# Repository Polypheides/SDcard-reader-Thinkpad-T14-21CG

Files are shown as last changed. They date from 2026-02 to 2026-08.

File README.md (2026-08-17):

# ⚠️ Disclaimer: Rev. 7 PCB Tested with Known Issues ⚠️

**Use at your own risk.** This is an experimental project. Rev. 7 has been hardware-verified to work, but requires a bodge wire fix.

> [!IMPORTANT]
> <details>
>   <summary><b>View Rev. 7 Bodge Wire Photo</b></summary>
>   <br>
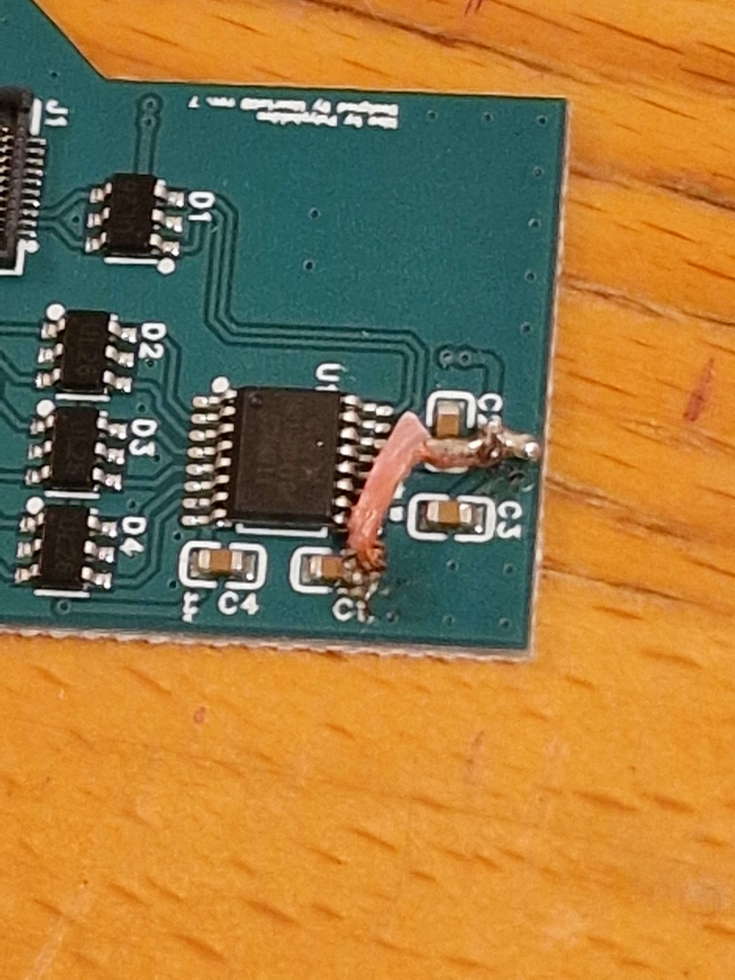
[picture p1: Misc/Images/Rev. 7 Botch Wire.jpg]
Rev. 7 Botch Wire
>   
> </details>

---

## Project Overview

This repository provides **Gerber files** for an internal MicroSD card reader daughterboard designed for the **ThinkPad T14 (Gen 3 / 21CG)**. It replaces the stock right-side single USB daughterboard.

### Technical Specifications

* **Controller:** Genesys Logic **GL823K** (USB 2.0 MicroSD Card Reader Controller).
* **ESD Protection:** **USBLC6-2SC6** monolithic ESD protection array.
  * **Data Integrity:** Ultra-low line capacitance (1 pF) prevents signal degradation on USB 2.0 differential pairs (D+/D-).
  * **Line Coverage:** Dedicated ESD clamping for data, clock, and command lines.
  * **Rail-to-Rail Clamping:** Suppresses high-voltage electrostatic discharge before transients reach the controller or internal hub.
* **Interface:** 20-pin FPC / board-to-board connector (`CON1`).
* **PCB Thickness:** Recommended **1.0 mm** for proper chassis clearance and alignment.

> [!NOTE]
> Rev.8 integrates the missing trace fix from Rev. 7 (eliminating the need for a jumper wire) and adds additional decoupling capacitors for power rail stability.

---

## Installation & Fitment Notes

* **Chassis Modification:** Physical filing or trimming of the laptop's plastic/magnesium subframe should not be required.
* **Connector Orientation:** Ensure **Pin 1** on the daughterboard aligns with **Pin 1** on the motherboard connector before applying power.

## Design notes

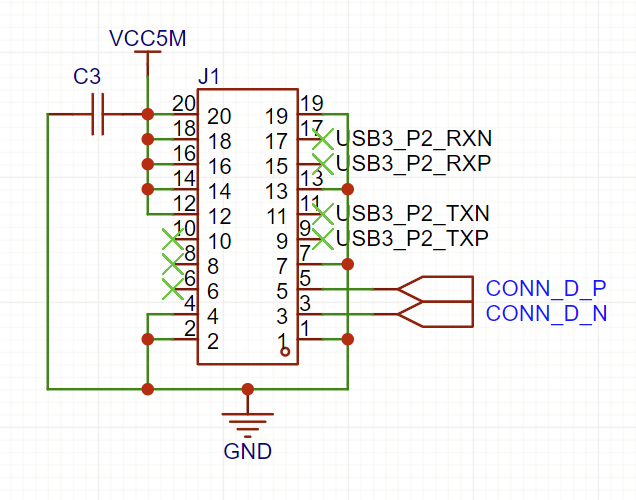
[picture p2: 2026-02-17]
Misc/Images/Connector Pinout.png

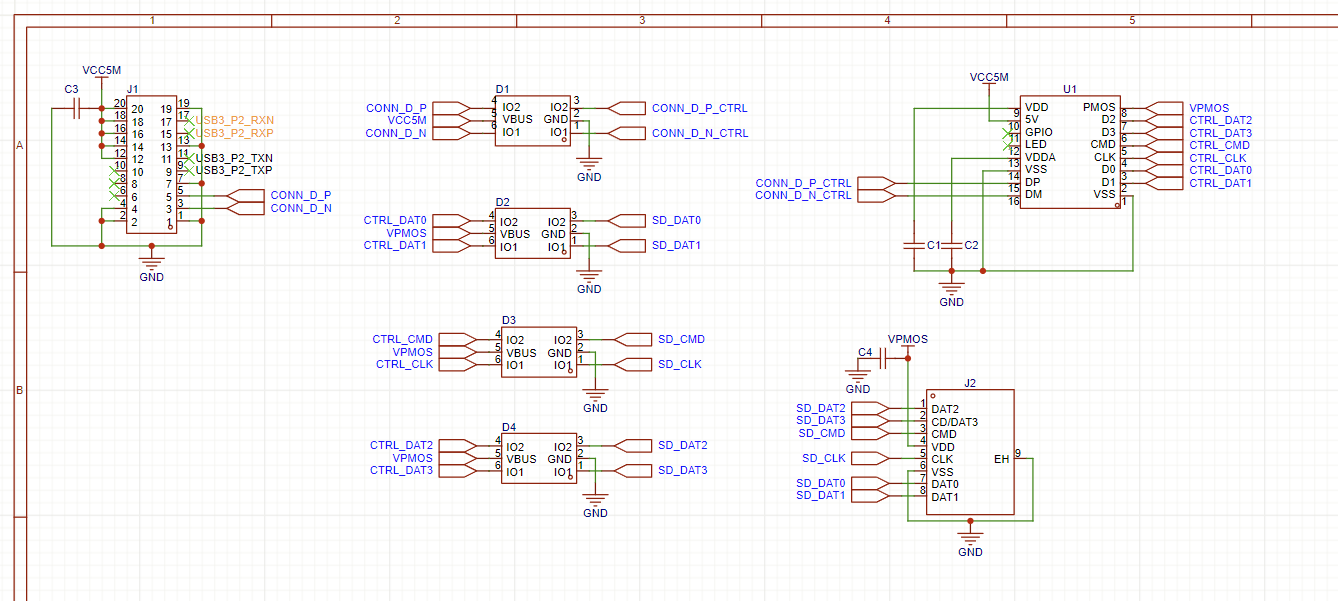
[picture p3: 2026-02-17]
Misc/Schematic/MuertoGB cleaned up Schematic.png

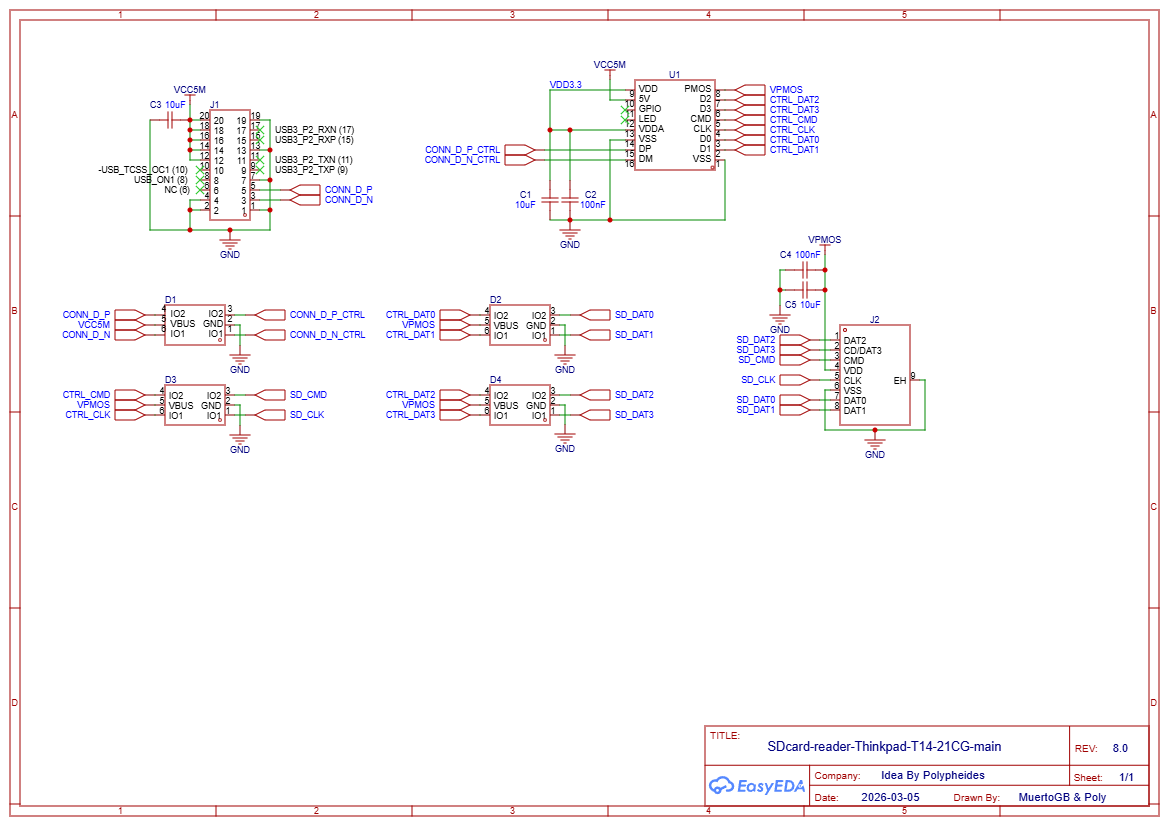
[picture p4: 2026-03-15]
Misc/Schematic/SCH_SD_pcb_t14_1-Sheet_1_2026-03-05.png

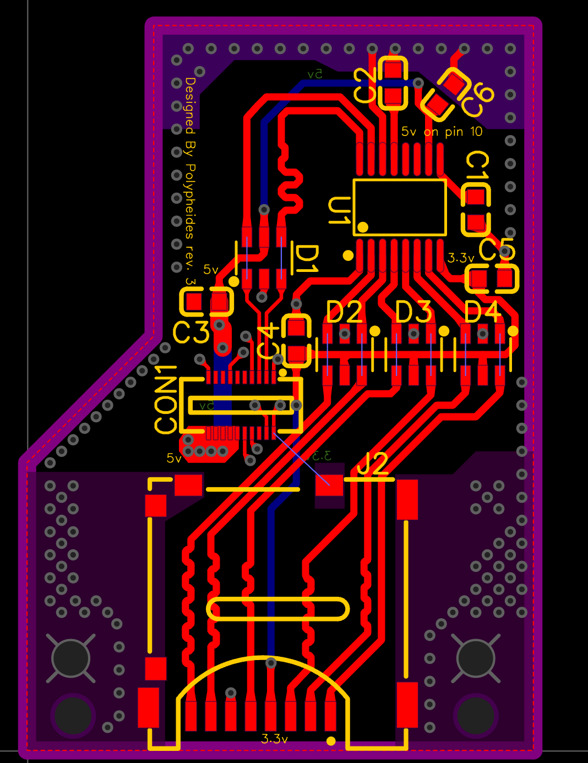
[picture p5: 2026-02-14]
Misc/Images/Rev3 example.png

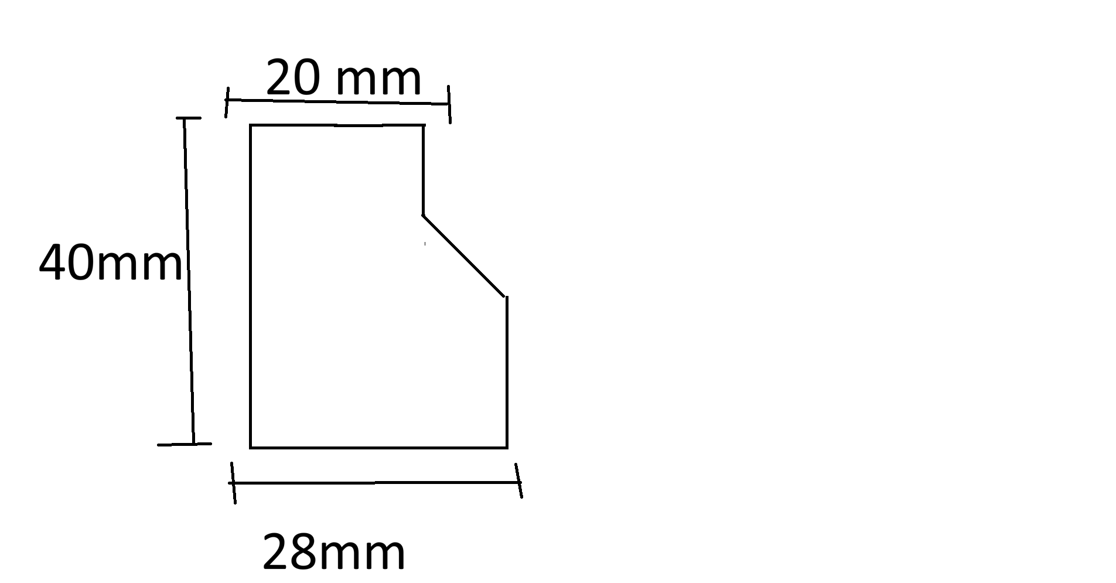
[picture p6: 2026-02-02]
Misc/Images/Dimentions.png

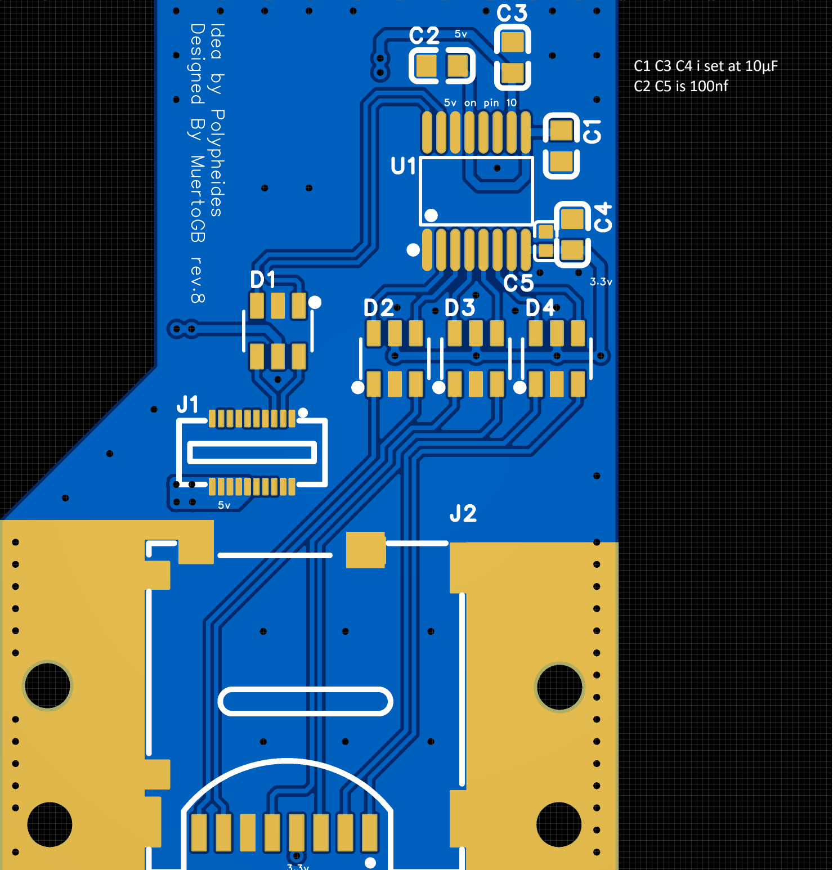
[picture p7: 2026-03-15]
Misc/Images/consept-of-Rev-8.png

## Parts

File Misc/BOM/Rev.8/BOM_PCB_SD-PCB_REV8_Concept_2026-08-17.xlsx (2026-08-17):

No. | Quantity | Comment | Designator | Footprint | Value | Manufacturer Part | Manufacturer | Supplier Part | Supplier
1 | 3 | 10uF | C1,C3,C4 | C0603 | 10uF | GRM188Z71A106KA73D | muRata(村田) | C2959727 | LCSC
2 | 1 | 100nF | C2 | C0603 |  | AC0603KRX7R8BB104 | YAGEO(国巨) | C327096 | LCSC
3 | 1 | 100nF | C5 | C0402 | 100nF | CC0402KRX7R7BB104 | YAGEO(国巨) | C60474 | LCSC
4 | 4 | USBLC6-2SC6_C2827654 | D1,D2,D3,D4 | SOT-23-6_L2.9-W1.6-P0.95-LS2.8-BL |  | USBLC6-2SC6 | TECH PUBLIC(台舟) | C2827654 | LCSC
5 | 1 | DF40C-20DS-0.4V(51) | J1 | CONN-SMD_20P-P0.40_DF40C-20DS-0.4V |  | DF40C-20DS-0.4V(51) | HRS(广濑) | C424638 | LCSC
6 | 1 | TF-009 | J2 | TF-SMD_TF-009 |  | TF-009 | SOFNG(硕方) | C428466 | LCSC
7 | 1 | GL823K-HCY04 | U1 | SSOP-16_L4.9-W3.9-P0.64-LS6.0-BL |  | GL823K-HCY04 | GENESYS(创惟) | C284879 | LCSC

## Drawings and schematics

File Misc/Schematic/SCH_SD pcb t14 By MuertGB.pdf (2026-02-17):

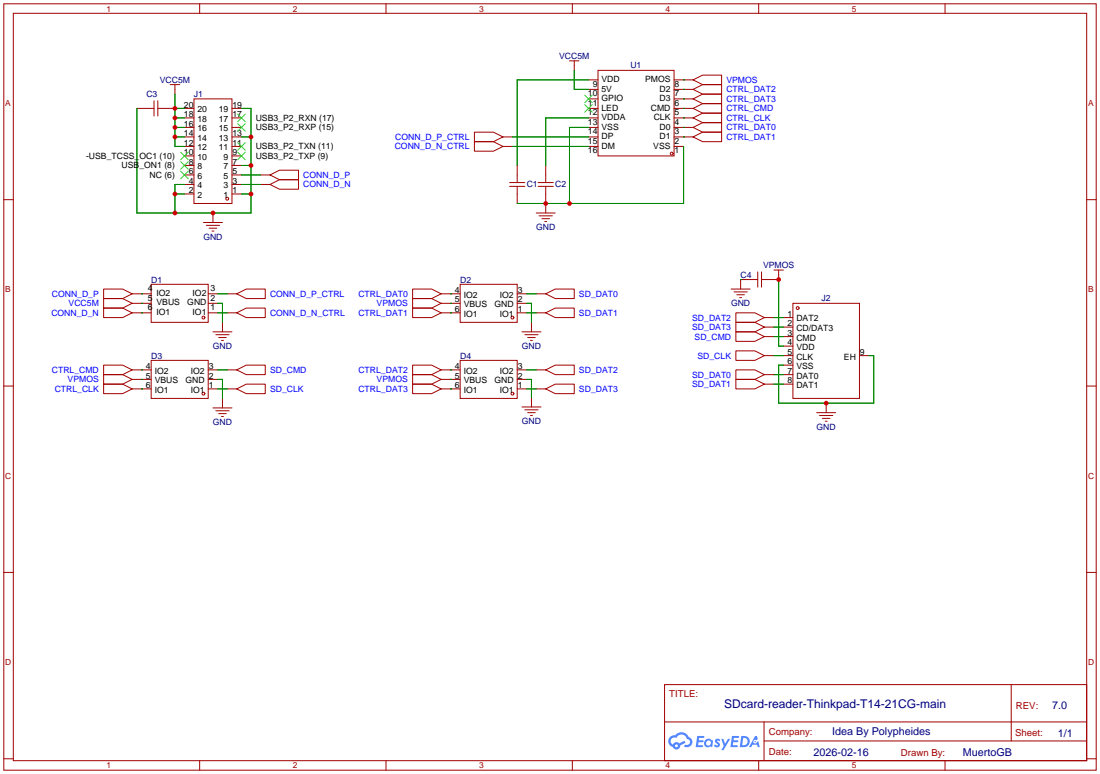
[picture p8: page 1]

VDD 9
5V 10 GPIO 11 LED 12 VDDA 13 VSS 14 DP 15 DM 16

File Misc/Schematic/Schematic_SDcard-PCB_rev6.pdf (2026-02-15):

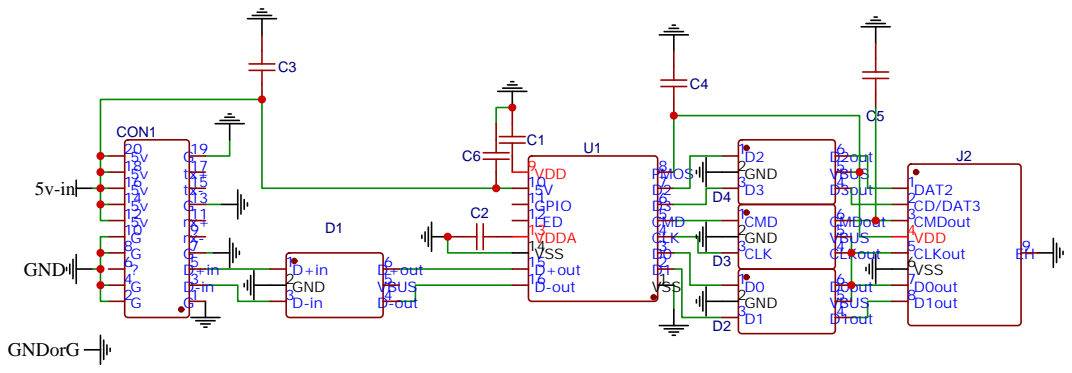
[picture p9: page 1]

Drawn By: Anders Johansson

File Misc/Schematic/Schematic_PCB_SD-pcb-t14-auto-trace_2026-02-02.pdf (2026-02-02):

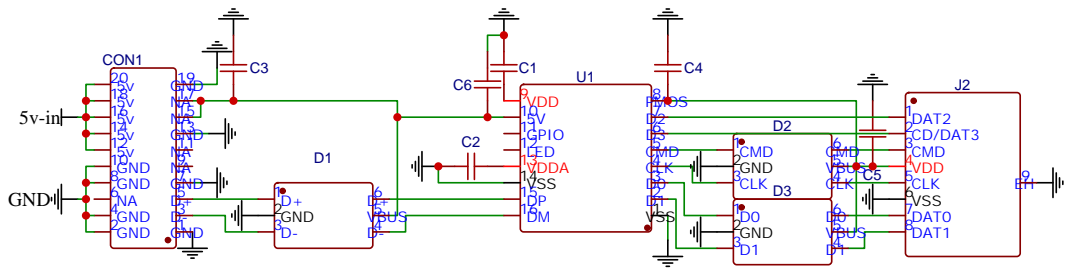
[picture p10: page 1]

Drawn By: Anders Johansson

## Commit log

2026-02-02 Initial Push
    [Drill_NPTH_Through.DRL, Drill_PTH_Through.DRL, Drill_PTH_Through_Via.DRL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]
2026-02-02 Extra Stuff
    [BOM_SD-pcb-t14_2026-01-29.csv, BOM_SD-pcb-t14_2026-02-01.csv]
2026-02-02 Moving gerber
    [Drill_NPTH_Through.DRL, Drill_PTH_Through.DRL, Drill_PTH_Through_Via.DRL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]
2026-02-17 Rev.7 Gerber/Schematic/BOM
    Adding a better optimized PCB and Schematic Designed by MuertoGB
    [BOM_SD pcb t14_PCB_SD-PCB_REV7_2026-02-17.xlsx, BOM_SD-pcb-t14_2026-01-29.csv, BOM_SD-pcb-t14_2026-02-01.csv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]
2026-02-17 Update PCB trace length.txt
2026-08-17 Rev. 8 Concept or Final Gerber/BOM/PnP
    Updated the README.md
    [BOM_PCB_SD-PCB_REV8_Concept_2026-08-17.xlsx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]
